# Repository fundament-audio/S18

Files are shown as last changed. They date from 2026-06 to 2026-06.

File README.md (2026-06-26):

# FUNDAMENT S18

**Deep 18″ bass without black boxes. Open, measurable, repairable — built to stay alive.**

> Status: 🟡 **Design + initial prototypes** — well proven DIY built.

Open-source sealed 18″ reference subwoofer. Build 001 of the [FUNDAMENT](https://github.com/fundament-audio/platform) platform.

💬 Main discussion lives on the [Audio Science Review thread](https://www.audiosciencereview.com/forum/index.php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) — come say hi.

## Scope

The S18 is a **music subwoofer**, best in pairs, crossed **as high as possible (≤ ~80–150/180 Hz)**. It is intentionally *not* a high-crossover mid woofer, directivity-controlled module — a single 18″ beams too early to integrate cleanly above that.

Deep, tactile bass with the cone control and low distortion to be taken seriously — not a home-theatre rumble box.

## Proven parts, missing data

The engineering here isn't novel - that's the point. The BMS 18N862 in a sealed ~120 L box is one of the most-trodden paths in serious DIY: documented across a scatter of forum builds, people raving about it, and a driver respected enough that designers like Troels Gravesen run it in their flagship full-range systems. The materials are known-good. By every account that exists, this driver is fast, low-distortion and properly excellent.

What's never existed is that knowledge in **one place, built to one spec, and measured to a published protocol** — instead of six forum posts and a dead image host.

Prior art tells us roughly where it lands. Measurements will follow and try to prove it.

## Target specs

| | |
|---|---|
| **Frequency response** | 20–250 Hz ±3 dB (ground plane, simulated), preset-dependent |
| **Typical in-room extension** | ~10 Hz (−6 dB, user reported & simulated) |
| **Max SPL** (avg 30–80 Hz, 1 m) | ~120 dB (simulated) |
| **Proprietary parts** | 0 | the last sub you'll ever need to fully buy! |
| **Dimensions (W×H×D)** | 550 × 550 × 600 mm |
| **Lifetime cost** | a fraction | of any commercial sub if anything fails — swap the part, not the system | 

## The recipe

| Part | Reference |
|---|---|
| **Driver** | BMS 18N862 |
| **Amp / DSP** | Hypex FusionAmp FA502 — or bring your own, see [`/dsp-amp`](dsp-amp/) |
| **Enclosure** | Sealed, ~115–125 L net |
| **Alignment** | Fc ≈ 47 Hz, **Qtc ≈ 0.64** |
| **Crossover** | User-set in processor/pre-amp; ships full-range to natural roll-off |
| **EQ** | Switchable presets — extension vs. SPL |

Off-the-shelf parts only. No custom tooling.

The Hypex is the validated reference. Alternative amps (Crown XLS, DIY Purifi/nCore, Audiophonics) and DSPs (miniDSP, Raspberry Pi + CamillaDSP, a ~€30 Pico 2 + Arylic, Behringer DCX2496) are documented in [`/dsp-amp`](dsp-amp/).

## Built to stay alive

Nothing here is a sealed black box. Driver, amp, DSP, enclosure, tuning and measurements are all documented, versioned and replaceable. Driver dies — replace it. Amp dies — swap it. Want a different target? Validate it, publish the data: same platform, different validated outcome.

## How to get one

| Path | What it means |
|---|---|
| **DIY** | Download files, source parts, build it all |
| **Part-DIY** | Plans + flatpack or local CNC, assemble yourself |
| **Local build** | Cabinets or parts made locally from the open files |
| **Built-to-order** | Future: hand-built systems from the same open design |

Built-to-order is convenience, not a paywall. The engineering stays open.

Rough cost per build (and per stereo pair) → [`/bom`](bom/).

## Repository map

```text
S18/
├── drivers/        # driver choices, targets and use cases
├── dsp-amp/        # DSP + amplifier paths, presets and protection
├── enclosure/      # cabinet design, cut list, bracing and DXF
├── measurements/   # simulations, ground-plane data and future measurements
├── bom/            # bill of materials and suppliers
├── docs/           # build guide and design notes
└── README.md
```

Start here:

* [drivers/](drivers/) — choose the driver path
* [dsp-amp/](dsp-amp/) — choose DSP / amplifier implementation
* [enclosure/](enclosure/) — build the cabinet
* [measurements/](measurements/) — check simulation and measured data
* [bom/](bom/) — source parts
* [docs/BUILD.md](docs/BUILD.md) — build guide

## Built on FUNDAMENT

This repo is one implementation; the platform defines how it thinks: [PHILOSOPHY](https://github.com/fundament-audio/platform/blob/main/PHILOSOPHY.md) · [DECISION_MODEL](https://github.com/fundament-audio/platform/blob/main/DECISION_MODEL.md) · [MEASUREMENT_PROTOCOL](https://github.com/fundament-audio/platform/blob/main/MEASUREMENT_PROTOCOL.md) · [DOCUMENTATION_STANDARD](https://github.com/fundament-audio/platform/blob/main/DOCUMENTATION_STANDARD.md).

## Contributing

Build it, measure it to the protocol, share the data. Independent measurements especially welcome — see [`CONTRIBUTING.md`](CONTRIBUTING.md). Roadmap and revisions tracked through GitHub issues + PRs.

💬 Main discussion lives on the [Audio Science Review thread](https://www.audiosciencereview.com/forum/index.php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) — come say hi.

## Licence

Designs CERN-OHL-S-2.0 · docs/measurements CC-BY-SA-4.0 · code MIT.

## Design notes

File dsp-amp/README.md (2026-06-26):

# S18 — DSP & amplification

The S18 ships **full-range** to its natural roll-off. You choose how to power and shape it — amp and DSP are modular.

## Reference — Hypex FusionAmp FA502 ✅

Amp + DSP + limiter in one box, and the **only path we've validated so far**. Load our HFD presets and you're done → [`bms-18n862/hypex`](bms-18n862/hypex/).

Everything below is **documented as compatible, not measured by us** — each option *can* apply the same presets (a Butterworth high-pass + the 20 Hz PEQ, ideally with a limiter). If you build and measure one, publish the data and we'll fold it in.

## Amplifier options

For when you're not running the FA502. Only the Crown XLS has its own DSP; the rest are **amp-only** and need a DSP from the next section.

| Amp | DIY / turnkey | Onboard DSP? | Notes | Cost |
|---|---|---|---|---|
| **Hypex FA502** ✅ | turnkey plate amp | yes (+ limiter) | the reference — amp + DSP in one box | €€ |
| **[Crown XLS DriveCore 2](https://www.crownaudio.com/en-US/products/xls-1002)** (1002/1502/2002) | turnkey pro amp | **yes** — PEQ + HP/LP to 24 dB/oct + Peakx limiter, presets persist | can host our presets standalone; measures a step below the Class-D references and has a fan — the gap shows more if you cross higher | € |
| **[Hypex nCore module](https://www.hypex.nl/products/amplifier-families/mains-powered-ncore-family/nc502mp-oem)** (NC252MP / NC502MP) | DIY module | no | same Class-D as the FA502, minus the DSP; superb measurements; pair with a DSP | €€ (~€375 module) |
| **[Purifi Eigentakt 1ET400A](https://purifi-audio.com/eigentakt)** | DIY module | no | about the best-measuring there is; needs SMPS + input buffer + chassis | €€€€ |
| **[Audiophonics assembled](https://www.audiophonics.fr/en/audiophonics-workshop-amplifiers-c-6421.html)** (LPA-S400ET Purifi · AP300-S500NC nCore) | turnkey (EU) | no | built boxes if you want Purifi/nCore without soldering | €€€ |
| **Any competent amp** | — | no | the driver is just a driver — ~500 W / 4 Ω class, stable and low-noise; pair with a DSP | varies |

Hypex owns the hi-fi "amp + DSP in one box" niche. **Purifi and Pascal are amp *modules* only** — there's no hi-fi DSP plate amp from either. (Pro Pascal + Marani DSP / Four Audio PPA plate amps exist, but they're install-grade and out of scope here.) So beyond the Hypex, your only integrated-DSP amp is the Crown XLS; everything else is amp + a separate DSP.

## DSP options

For any amp-only chain, the DSP applies the presets: a Butterworth high-pass (15/20/30 Hz, 24 dB/oct) plus the ~20 Hz PEQ boost, ideally with a protection limiter. The per-driver values in [`bms-18n862/`](bms-18n862/) are the source of truth.

| DSP | Type | HP 24 dB/oct + PEQ + limiter? | Notes | Cost |
|---|---|---|---|---|
| **[miniDSP 2x4 HD / Flex](https://www.minidsp.com/products/minidsp-in-a-box/minidsp-2x4-hd)** | dedicated | yes — all three | purpose-built for exactly this; standalone; clean — the easy recommendation | €€ |
| **Raspberry Pi + DAC HAT + [CamillaDSP](https://github.com/HEnquist/camilladsp)** | computer-based | yes (CamillaDSP biquads) | open and flexible; best-measuring HATs e.g. [HiFiBerry](https://www.hifiberry.com) DAC2 HD / DAC8x; some setup | € |
| **[DSPi](https://github.com/WeebLabs/DSPi) on a Raspberry Pi Pico 2 + Arylic ES9023 I2S DAC** | microcontroller | PEQ + crossovers yes; limiter ⚠️ verify | a full modern DSP for **~€30 all-in** — wild value for tinkerers; any decent I2S DAC works, the Arylic ES9023 is the cheap known-good one | € |
| **[Behringer Ultradrive DCX2496](https://www.behringer.com/en/products/0825-AAA)** | dedicated (pro) | yes — BW/Bessel/LR 6–48 dB/oct + PEQ + limiter | cheap and capable; dated/noisy analog I/O — feed it digitally if you can | € (~€300) |
| **[MOTU UltraLite-mk5](https://motu.com/en-us/products/gen5/ultralite-mk5/)** (or similar studio interface) | studio interface | PEQ + dynamics yes; steep HP ⚠️ approximate | runs standalone after config; a true 24 dB/oct protective HP isn't a normal PEQ band — lean on its dynamics/limiter, or use a dedicated DSP for the protective filter | €€€ |

Whatever you pick, apply the high-pass + PEQ from [`bms-18n862/`](bms-18n862/) and make sure a **working limiter sits somewhere in the chain** — see Protection below.

## How this folder is organized

DSP settings are modular — per driver, then per amp/DSP:

- **`dsp-amp/<driver>/`** — the DSP settings (target curves / EQ presets) for that driver. This is the source of truth, amp-agnostic.
- **`dsp-amp/<driver>/<dsp>/`** — ready-to-load files and notes for one specific amp/DSP (e.g. Hypex HFD presets).

The amp/DSP alternatives above are a documented menu for now; a `<driver>/<dsp>/` folder gets created once an option is validated with real files — as [`bms-18n862/hypex/`](bms-18n862/hypex/) is.

### Drivers

- **[`bms-18n862/`](bms-18n862/)** — the three EQ presets (extension vs. SPL) for the BMS 18N862.
  - [`bms-18n862/hypex/`](bms-18n862/hypex/) — Hypex FA502 HFD files + loading notes.

## Protection — do not disable

The onboard limiter is the safety-critical part of this design. Because room EQ runs *upstream*, the amp must survive whatever you feed it — a single null-fill boost can otherwise bottom the driver. This applies on every amp/DSP path, not just the Hypex.

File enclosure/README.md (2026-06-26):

# S18 — Enclosure

Sealed cabinet for the BMS 18N862.

| | |
|---|---|
| **Type** | Sealed |
| **Net volume** | ~115–125 L |
| **Alignment** | Fc ≈ 47 Hz, Qtc ≈ 0.64 |
| **Material** | 22 mm MDF (this iteration) |
| **External (W×H×D)** | 550 × 550 × 602 mm |

**Construction:** double front baffle, 3× window brace, full damping stack, corner fillets. All panels 22 mm MDF.

## Cut list

All panels 22 mm MDF. Dimensions in mm.

| Part | Qty | Size | Cutout |
|---|---|---|---|
| Outer baffle | 1 | 550×550 | Ø460 |
| Inner baffle | 1 | 550×550 | Ø418 |
| Rear | 1 | 550×550 | Optional terminal |
| Side | 2 | 536×550 | None |
| Top | 1 | 506×536 | None |
| Bottom | 1 | 506×536 | None |
| Window brace | 2 | 506×536 | As seen in DXF |

## Damping

- **Panels:** bitumen pads on the side walls to kill panel ring.
- **Fill:** Visaton VS-Wool acoustic wool. Fill the cabinet evenly — **not too tight, but still present** throughout. Light, even fill tames internal standing waves without over-stuffing (which would skew the sealed alignment).

## Plans

**Cut files (DXF):** first CNC iteration, including the window braces → [`dxf/fundament-s18-with-braces.dxf`](dxf/fundament-s18-with-braces.dxf). All other files live in [`/enclosure/dxf`](dxf/).

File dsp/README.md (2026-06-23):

# S18 — DSP & amplification

The S18 ships **full-range** to its natural roll-off. You choose how to power and shape it.

## Paths

**1. Hypex FusionAmp FA502 — the easy entrance** (recommended for now)
Amp + DSP in one box. Load our HFD presets and you're done — see the files below.

**2. Bring your own amp** — ⏳
The driver is just a driver: any competent amp with adequate power and control works. Pair it with a DSP path.

**3. Bring your own DSP** — ⏳
Have a separate processor (miniDSP, CamillaDSP, …)? Apply our target curves / biquad coefficients on your own platform.

## The three presets

Three presets, switchable on the Hypex, trading low-frequency extension against maximum SPL. Each pairs a **Linkwitz-style PEQ boost at 20 Hz** (to extend the sealed roll-off) with a **Butterworth high-pass** that sets the excursion limit and protects the driver.

### S18 Deep — maximum extension
Lowest reach, lowest max SPL. For smaller rooms, or when you want the bottom octave over loudness.

| | |
|---|---|
| **High-pass** | 15 Hz · Butterworth · 24 dB/oct |
| **PEQ** | 20 Hz · +15.0 dB · Q 1.6 |
| **Simulated (ground plane)** | F3 20.4 Hz · F6 ~18 Hz · F10 16.1 Hz |
| **Max SPL (sim)** | 106.4 dB |
| **Ground plane (measured)** | ⏳ pending |
| **In-room (measured)** | ⏳ pending |

### S18 — balanced (default)
The all-rounder: sensible extension with healthy headroom.

| | |
|---|---|
| **High-pass** | 20 Hz · Butterworth · 24 dB/oct |
| **PEQ** | 20 Hz · +10.5 dB · Q 1.1 |
| **Simulated (ground plane)** | F3 29.8 Hz · F6 ~25 Hz · F10 19.8 Hz |
| **Max SPL (sim)** | 114.0 dB |
| **Ground plane (measured)** | ⏳ pending |
| **In-room (measured)** | ⏳ pending |

### S18 Loud — maximum output
Loudest, rolls off earliest. For larger rooms, or when you want SPL over the last octave.

| | |
|---|---|
| **High-pass** | 30 Hz · Butterworth · 24 dB/oct |
| **PEQ** | 20 Hz · +10.0 dB · Q 1.3 |
| **Simulated (ground plane)** | F3 37.7 Hz · F6 ~32 Hz · F10 26.2 Hz |
| **Max SPL (sim)** | 120.0 dB |
| **Ground plane (measured)** | ⏳ pending |
| **In-room (measured)** | ⏳ pending |

### Summary

| Preset | High-pass (BW, 24 dB/oct) | PEQ @ 20 Hz | F3 sim (Hz) | F6 sim (Hz)* | F10 sim (Hz) | Max SPL (sim) | F3 ground plane (meas.) | F3 in-room (meas.) |
|---|---|---|---|---|---|---|---|---|
| **S18 Deep** | 15 Hz | +15.0 dB, Q 1.6 | 20.4 | ~18 | 16.1 | 106.4 dB | | |
| **S18** | 20 Hz | +10.5 dB, Q 1.1 | 29.8 | ~25 | 19.8 | 114.0 dB | | |
| **S18 Loud** | 30 Hz | +10.0 dB, Q 1.3 | 37.7 | ~32 | 26.2 | 120.0 dB | | |

\* F3 and F10 are read from the simulation; F6 is interpolated between them. Ground-plane and in-room columns are ⏳ pending measurement.

### Ground plane vs in-room

The figures above are **simulated ground-plane** (anechoic/electrical) targets. In a real room, **room gain** lifts the bottom octave further — typical usable **in-room extension is ~10 Hz (−3 dB)**. So the right preset depends on your room's gain as much as taste. HFDs are pure software presets, so we'll follow up with measurements and iterate here :)

## The files

- HFD presets → [`/dsp/hypex`](hypex/)
- The EQ settings above are the source of truth; per-preset target curves + full biquad allocation → ⏳ pending.
- Crossover is **user-set upstream** in the processor/pre-amp; nothing is baked into the DSP.

## Protection — do not disable

The onboard limiter is the safety-critical part of this design. Because room EQ runs *upstream*, the amp must survive whatever you feed it — a single null-fill boost can otherwise bottom the driver.

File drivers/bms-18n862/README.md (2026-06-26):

# S18 — Driver: BMS 18N862

The driver is a modular component of the S18. This page is the hub for the **BMS 18N862** in the S18 sealed enclosure: what it's for, the target it's designed to hit, and where to find its DSP settings and measurements.

## Design goal (read this first)

In the S18 enclosure, the 18N862 is tuned as a **music subwoofer**, designed to ideally work in pairs — crossed **as high as possible (≤ ~80–120 Hz)**. The goal is tactile, high-fidelity low end: chest-slam and grunt with the cone control and low distortion to integrate cleanly with mains.

It is intentionally *not* a high-crossover, directivity-controlled module — a single 18″ beams too early to integrate cleanly above that — and *not* a pure LFE box crossed at 50 Hz. Other targets are possible on the same cabinet; this driver is documented for the music-pair target.

## Target specs

| | |
|---|---|
| **Frequency response** | 20–250 Hz ±3 dB (ground plane), preset-dependent |
| **Typical in-room extension** | ~10 Hz (−3 dB) |
| **Max SPL** (avg 30–80 Hz, 1 m) | ~120 dB |

Extension vs. SPL is set by the DSP preset — see [`/dsp-amp/bms-18n862`](../../dsp-amp/bms-18n862/).

## Alignment in the S18 enclosure

| | |
|---|---|
| **Type** | Sealed, ~115–125 L net |
| **Alignment** | Fc ≈ 47 Hz, **Qtc ≈ 0.64** |

Cabinet design and cut list → [`/enclosure`](../../enclosure/).

## Thiele/Small parameters

⏳ pending — to be published from datasheet + per-unit verification (see the measurements protocol). Per-unit T/S verification is tracked under [`/measurements`](../../measurements/).

## Where to go next

- **DSP settings / EQ presets** for this driver → [`/dsp-amp/bms-18n862`](../../dsp-amp/bms-18n862/)
- **Enclosure** it runs in → [`/enclosure`](../../enclosure/)
- **Measurements** (simulated + measured) → [`/measurements/0-simulation/bms-18n862`](../../measurements/0-simulation/bms-18n862/)

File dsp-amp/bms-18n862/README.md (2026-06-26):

# S18 — DSP settings: BMS 18N862

DSP settings for the **BMS 18N862** in the S18 sealed enclosure. These are the **source of truth** — amp-agnostic target curves. For ready-to-load files on a specific amp, see [`hypex/`](hypex/) (or apply the biquads on your own DSP).

For the driver's design target and specs, see the driver hub → [`../../drivers/bms-18n862`](../../drivers/bms-18n862/).

## The three presets

Three presets, trading low-frequency extension against maximum SPL. Each pairs a **Linkwitz-style PEQ boost at 20 Hz** (to extend the sealed roll-off) with a **Butterworth high-pass** that sets the excursion limit and protects the driver.

### S18 Deep — maximum extension
Lowest reach, lowest max SPL. For smaller rooms, or when you want the bottom octave over loudness.

| | |
|---|---|
| **High-pass** | 15 Hz · Butterworth · 24 dB/oct |
| **PEQ** | 20 Hz · +15.0 dB · Q 1.6 |
| **Simulated (ground plane)** | F3 20.4 Hz · F6 ~18 Hz · F10 16.1 Hz |
| **Max SPL (sim)** | 106.4 dB |
| **Ground plane (measured)** | ⏳ pending |
| **In-room (measured)** | ⏳ pending |

### S18 — balanced (default)
The all-rounder: sensible extension with healthy headroom.

| | |
|---|---|
| **High-pass** | 20 Hz · Butterworth · 24 dB/oct |
| **PEQ** | 20 Hz · +10.5 dB · Q 1.1 |
| **Simulated (ground plane)** | F3 29.8 Hz · F6 ~25 Hz · F10 19.8 Hz |
| **Max SPL (sim)** | 114.0 dB |
| **Ground plane (measured)** | ⏳ pending |
| **In-room (measured)** | ⏳ pending |

### S18 Loud — maximum output
Loudest, rolls off earliest. For larger rooms, or when you want SPL over the last octave.

| | |
|---|---|
| **High-pass** | 30 Hz · Butterworth · 24 dB/oct |
| **PEQ** | 20 Hz · +10.0 dB · Q 1.3 |
| **Simulated (ground plane)** | F3 37.7 Hz · F6 ~32 Hz · F10 26.2 Hz |
| **Max SPL (sim)** | 120.0 dB |
| **Ground plane (measured)** | ⏳ pending |
| **In-room (measured)** | ⏳ pending |

### Summary

| Preset | High-pass (BW, 24 dB/oct) | PEQ @ 20 Hz | F3 sim (Hz) | F6 sim (Hz)* | F10 sim (Hz) | Max SPL (sim) | F3 ground plane (meas.) | F3 in-room (meas.) |
|---|---|---|---|---|---|---|---|---|
| **S18 Deep** | 15 Hz | +15.0 dB, Q 1.6 | 20.4 | ~18 | 16.1 | 106.4 dB | | |
| **S18** | 20 Hz | +10.5 dB, Q 1.1 | 29.8 | ~25 | 19.8 | 114.0 dB | | |
| **S18 Loud** | 30 Hz | +10.0 dB, Q 1.3 | 37.7 | ~32 | 26.2 | 120.0 dB | | |

\* F3 and F10 are read from the simulation; F6 is interpolated between them. Ground-plane and in-room columns are ⏳ pending measurement.

### Ground plane vs in-room

The figures above are **simulated ground-plane** (anechoic/electrical) targets. In a real room, **room gain** lifts the bottom octave further — typical usable **in-room extension is ~10 Hz (−3 dB)**. So the right preset depends on your room's gain as much as taste. HFDs are pure software presets, so we'll follow up with measurements and iterate here :)

## The files

- **Hypex FA502 HFD presets** → [`hypex/`](hypex/)
- The EQ settings above are the source of truth; per-preset target curves + full biquad allocation → ⏳ pending.
- **Bring your own DSP:** apply the high-pass + PEQ above on your platform.
- Crossover is **user-set upstream** in the processor/pre-amp; nothing is baked into the DSP.

## Protection — do not disable

The onboard limiter is the safety-critical part of this design. Because room EQ runs *upstream*, the amp must survive whatever you feed it — a single null-fill boost can otherwise bottom the driver. (See the [DSP & amplification overview](../).)

## Where to go next

- **Driver hub** (target + specs) → [`../../drivers/bms-18n862`](../../drivers/bms-18n862/)
- **Simulation** these presets are derived from → [`../../measurements/0-simulation/bms-18n862`](../../measurements/0-simulation/bms-18n862/)

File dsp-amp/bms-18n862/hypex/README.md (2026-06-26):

# S18 — Hypex FA502 (BMS 18N862)

Ready-to-load presets for the **Hypex FusionAmp FA502** driving the BMS 18N862. These implement the three target curves documented one level up → [`../`](../).

## The HFD files

⏳ pending — one `.hfd` per preset (S18 Deep / S18 / S18 Loud).

## Loading a preset

1. Open the Hypex Filter Designer (HFD) and connect to the FA502.
2. Load the `.hfd` for the preset you want.
3. Verify the **limiter is active** before playing — see below.

## Protection — do not disable

The onboard limiter is safety-critical. Room EQ runs **upstream** of the amp, so the FA502 must survive whatever it's fed — a single null-fill boost can bottom the driver if the limiter is off. Keep it enabled on every preset.

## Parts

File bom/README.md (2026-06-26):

# S18 — Bill of materials

> **First stab.** Prices are *indicative* — a rough "what will this cost me" feel, not quotes.
> Confirm current/local pricing before buying. EU (€, Germany reference) is firmest; UK/NA/Asia are
> approximate. `unknown` means we haven't found a reliable figure yet. EU prices are roughly inc-VAT
> unless noted. Off-the-shelf parts only — no custom tooling.

## What varies, what doesn't

- **Per cabinet, shared across builds:** driver, enclosure material, damping, connectors, fixings.
- **The modular cost:** amp/DSP — see [`/dsp-amp`](../dsp-amp/). Your choice here drives most of the
  total *and* the stereo economics (one stereo amp / one multi-output DSP can serve both subs).

## Sourcing & prices — big-ticket items

### Driver — BMS 18N862 (8 Ω)
*BMS Speakers GmbH, Hannover — not the unrelated Shenzhen "BMS Audio".*

| Region | ~Price | Where to buy |
|---|---|---|
| EU | ~€600 (range €460–740) | [Toutlehautparleur](https://en.toutlehautparleur.com/speaker-bms-18n862-8-ohm-18-inch.html) (FR), Knockoutsound |
| UK | ~£450–600 | [Elements Audio](https://www.elements-audio.com) (~£450), [Lean Audio](https://leanaudio.co.uk/product/bms-18n862-8-ohm-18-1500w-loudspeaker/) (~£600) |
| NA | ~$600 | US Speaker LLC, Reverb |
| Asia | unknown | [BMS Asia-Pacific distributors](https://www.bmsspeakers.com/index.php-791.html?id=bms_distributors_asia_pacific) |

### Reference amp + DSP — Hypex FusionAmp FA502
One box: amp + DSP + limiter. FA501 (single channel) ≈ €505 in the EU; other regions scale or `unknown`.

| Region | ~Price | Where to buy |
|---|---|---|
| EU | ~€720 inc (€585 ex VAT) | [Hypex Direct](https://www.hypexdirect.com/products/fusion-amplifiers/fusionamp-fa502), SoundImports (NL), Lautsprechershop (DE) |
| UK | ~£600–700 | Wilmslow Audio, Audio Hum, KJF Audio |
| NA | unknown US$ (≈$750 — confirm) | Hypex Direct (US), Madisound |
| Asia | unknown | Hypex Direct (ships JP/SG/MY/HK) / local distributor |

### Budget amp + DSP — Crown XLS 1502 DriveCore 2
Amp + onboard DSP in one box; the DSP can host our presets, and **one stereo unit drives a whole pair**.
See [`/dsp-amp`](../dsp-amp/) for the full amp/DSP menu (nCore, Purifi, miniDSP, Raspberry Pi, etc.).

| Region | ~Price | Where to buy |
|---|---|---|
| NA | ~$490–650 | Sweetwater, Parts-Express, Amazon |
| EU | ~€400–450 | Thomann |
| UK | ~£350–400 | Thomann UK |
| Asia | unknown | Thomann / local |

## Small parts (per cabinet)

Cheap, and similar across regions — EU figures shown.

| Part | Spec | Qty | ~EU | Notes |
|---|---|---|---|---|
| Damping wool | Visaton 5070 / VS-Wool (or equiv.) | a few packs | ~€10–40 | light, even fill — see [`/enclosure`](../enclosure/) |
| Panel damping | Self-adhesive bitumen pads | side panels | ~€30 | kills panel ring |
| Connector | Neutrik Speakon NL4 | 1 | ~€8 | optional rear terminal |
| Fixings | T-nuts/screws, sealant, glue | — | ~€20 | airtight assembly |

## Enclosure — by how you get the box

Cabinet ≈ **2.6 m² of 22 mm MDF** (from the [cut list](../enclosure/), 2 braces). Maps to the "How to
get one" paths in the [root README](../README.md):

| Path | What you do | ~Cost (Germany) |
|---|---|---|
| **DIY** — raw MDF | cut everything yourself | MDF ~€24/m² → **~€60/cab** |
| **Part-DIY** — precut plates | route the baffle cutouts + braces yourself | **~€70/cab** |
| **Local build** — full CNC | cutouts included | ~€60–70/m² → **~€160–180/cab** |
| **Built-to-order** — carpenter | hand-built cabinet | varies — **get a local quote** (rough order: a few hundred € of labour on top of materials) |

## Build totals (indicative, EU, precut box ~€70)

### Reference build — Hypex FA502
Per single sub: driver €600 + FA502 €700 + box €70 + damping €40 + Speakon €10 + fixings €20 ≈ **€1,440**.

Stereo pair — the amp choice is where you save or buy headroom:

| Pair amp config | Amps | Pair total | Note |
|---|---|---|---|
| 1× FA502 (one channel per sub) | ~€700 | ~€2,180 | cheapest Hypex; one amp drives both |
| 2× FA501 | ~€1,010 | ~€2,490 | one amp per sub |
| 2× FA502 bridged | ~€1,400 | ~€2,880 | ~1000 W/sub — max headroom |

### Budget build — no FA502
Stereo pair with **1× Crown XLS** (~€400) driving both ≈ **€1,880**. Or go cheaper on the DSP: a generic
~500 W amp + [DSPi on a Pico 2 + Arylic](../dsp-amp/) (~€30 DSP).

## Why a stereo pair is cheaper per sub

The per-sub cost drops as you add the second sub, because the amp/DSP can be **bought once**:

- A **stereo amp** (FA502, Crown XLS) drives both subs — one amp, not two.
- A **multi-output DSP** (miniDSP, Pico 2) processes both channels — bought once.
- The trade-off: a shared amp gives less per-sub headroom. **2× FA502 bridged** spends that saving back
  on ~1000 W/sub of headroom instead.

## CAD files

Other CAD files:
enclosure/dxf/fundament-s18-with-braces.dxf

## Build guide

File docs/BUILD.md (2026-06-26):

# S18 — Build guide

⏳ pending

Step-by-step, from cut to driver mounting to amp setup and loading the HFD:

1. Cut panels (see [`/enclosure`](../enclosure/)).
2. Assemble cabinet — bracing, damping stack, corner fillets.
3. Mount the BMS 18N862 driver (see [`/drivers/bms-18n862`](../drivers/bms-18n862/)).
4. Install and wire the Hypex FA502.
5. Load the HFD preset (see [`/dsp-amp/bms-18n862/hypex`](../dsp-amp/bms-18n862/hypex/)) and verify the limiter is active.

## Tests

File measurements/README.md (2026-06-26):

# S18 — Measurements

All raw data published. Protocol: see the platform [MEASUREMENT_PROTOCOL.md](https://github.com/fundament-audio/platform/blob/main/MEASUREMENT_PROTOCOL.md).

Measurements are modular like the rest of the build — data nests per **stage → driver → amp/DSP** (e.g. `0-simulation/bms-18n862/`).

| Measurement | Status |
|---|---|
| Simulated response (3 presets) | ✅ [`0-simulation/bms-18n862/`](0-simulation/bms-18n862/) · [live dashboard](https://simulator.00aud.io/app/share/18N862-125L-sealed-cmqpbl62e0003jp042uz99kmr) |
| Groundplane (anechoic-ish) | ⏳ pending |
| Nearfield (box response) | ⏳ pending |
| THD vs level (90/100/110 dB) | ⏳ pending |
| Long-term thermal compression | ⏳ pending |
| Per-unit T/S verification | ⏳ pending |
| Independent (Klippel NFS / anechoic) | 🙏 wanted — get in touch |

**Honest expectations:** clean to ~110 dB in the passband; THD rises below ~30 Hz at high SPL.

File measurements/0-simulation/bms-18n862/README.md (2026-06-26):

# S18 — 0 · Simulation

Initial sealed-box simulation of the BMS 18N862 in ~125 L sealed, including the three DSP presets.

**Live dashboard:** <https://simulator.00aud.io/app/share/18N862-125L-sealed-cmqpbl62e0003jp042uz99kmr>

## Results (simulated, ground plane)

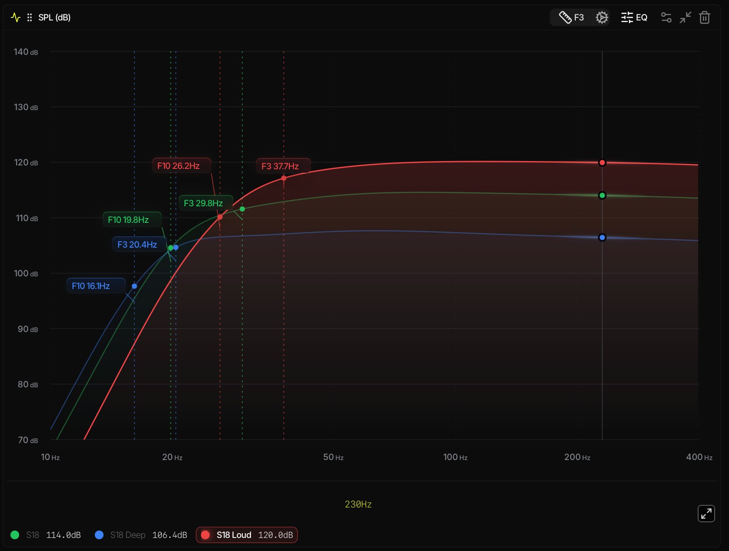
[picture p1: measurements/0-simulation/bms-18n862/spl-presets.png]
SPL vs frequency for all three presets


| Preset | F3 (Hz) | F6 (Hz) | F10 (Hz) | Max SPL |
|---|---|---|---|---|
| S18 Deep | 20.4 | ~18 | 16.1 | 106.4 dB |
| S18 | 29.8 | ~25 | 19.8 | 114.0 dB |
| S18 Loud | 37.7 | ~32 | 26.2 | 120.0 dB |

Full EQ settings (high-pass + PEQ) per preset → [`/dsp-amp/bms-18n862`](../../../dsp-amp/bms-18n862/).

## EQ per preset

**S18 Deep** — PEQ 20 Hz +15.0 dB Q 1.6 · HP 15 Hz BW 24 dB/oct

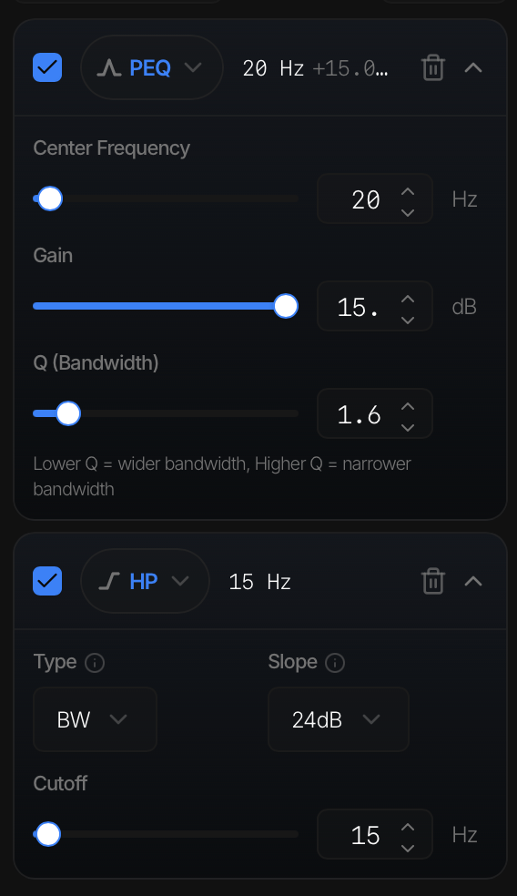
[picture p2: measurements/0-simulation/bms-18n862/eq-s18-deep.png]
S18 Deep EQ


**S18** (balanced) — PEQ 20 Hz +10.5 dB Q 1.1 · HP 20 Hz BW 24 dB/oct

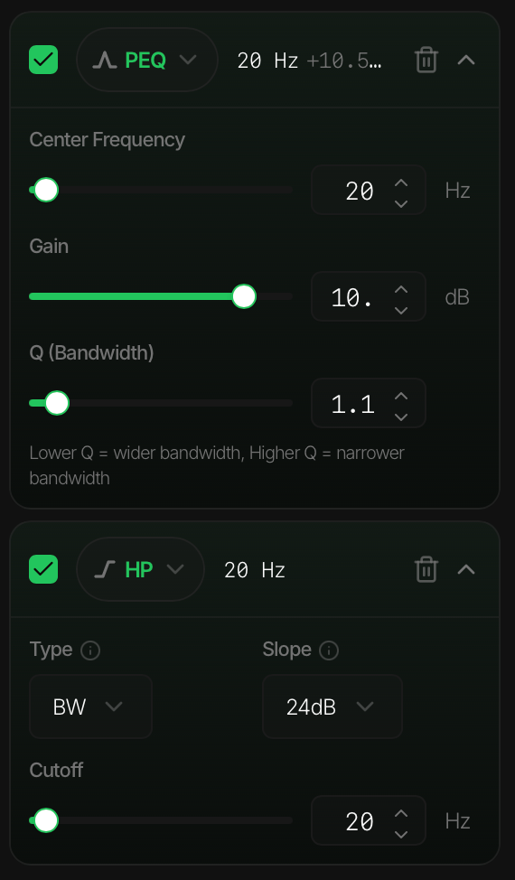
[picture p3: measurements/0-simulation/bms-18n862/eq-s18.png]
S18 EQ


**S18 Loud** — PEQ 20 Hz +10.0 dB Q 1.3 · HP 30 Hz BW 24 dB/oct

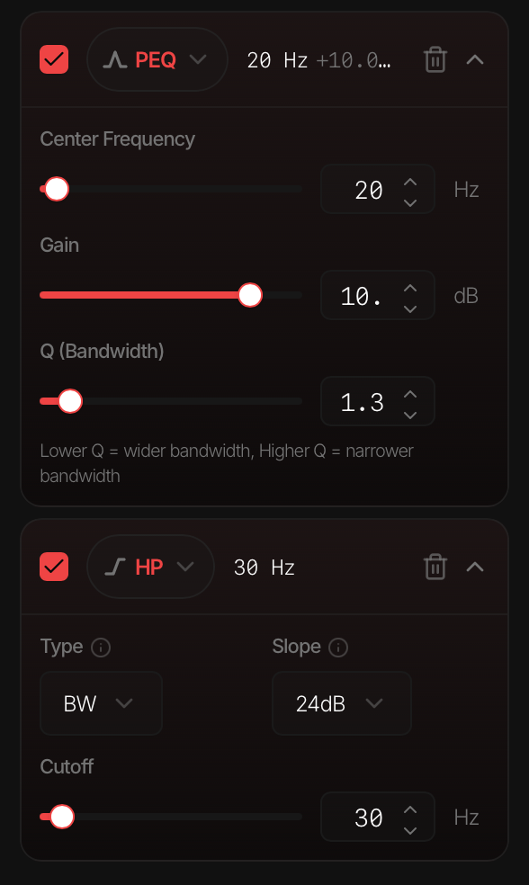
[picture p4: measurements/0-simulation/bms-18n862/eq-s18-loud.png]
S18 Loud EQ


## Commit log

2026-06-23 chore: restructure docs and add enclosure cutout list
2026-06-26 Update driver references in README.md
2026-06-26 chore: add enclosure dxf
    [fundament-s18-with-braces.dxf]
2026-06-26 chore/add-enclosure guides
2026-06-26 adding first BOM stab
